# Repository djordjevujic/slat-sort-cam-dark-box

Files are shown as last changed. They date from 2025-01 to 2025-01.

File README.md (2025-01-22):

# slat-sort-cam-dark-box

Box used to hold a camera system, providing an initially dark environment and an adjustable lighting system.

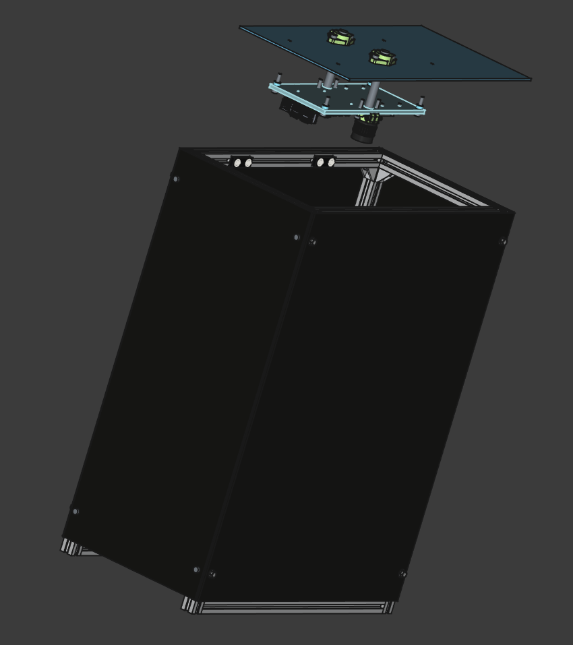
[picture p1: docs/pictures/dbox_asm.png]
Dark Box Assembly


## Project Overview

This project is developed in **FreeCAD 1.0.0**.

- **Main File**: The primary design file is `dbox_asm.FCStd`, located in the `assembly` folder.
- **Documentation**: Parts and material ordering documentation can be found in the `docs` folder.

## Features

- **Dark Environment**: Ensures initial dark conditions for precise image capture or experimentation.
- **Adjustable Lighting**: Includes a lighting system with customizable settings for controlled illumination.
- **Compact Design**: Optimized for portability and minimal footprint.
- **Light Isolation**: Prevents external light interference for consistent imaging.

## Applications

- Precision imaging for machine vision systems.
- Testing and calibrating camera sensors in controlled environments.
- Scientific experiments requiring adjustable lighting.

## Getting Started

### Prerequisites

- Install **FreeCAD 1.0.0** or a compatible version.
- Ensure all required materials and tools for assembly are available.

### Assembly Instructions

1. Open the `dbox_asm.FCStd` file in FreeCAD.
2. Follow the assembly instructions included in the `docs` folder.
3. Install the camera and lighting system inside the box.

## Usage

- Place the camera in the designated area within the box  - see `cam_holder_plate.FCStd`and `cam_holder_mount.FCStd`.
- Adjust the lighting system using the provided controls to meet your requirements.

## Documentation

- **Parts List and Material Ordering**: Detailed documentation is located in the `docs` folder.
  - Includes specifications for parts and ordering information.
  - Refer to the included files for a complete overview.

## License

This project is licensed under the **GNU General Public License (GPL)**. 

You are free to use, modify, and distribute the project under the terms of the GPL license. However, any derivative work must also be released under the same license. For more details, see the [GPL License](https://www.gnu.org/licenses/gpl-3.0.html).

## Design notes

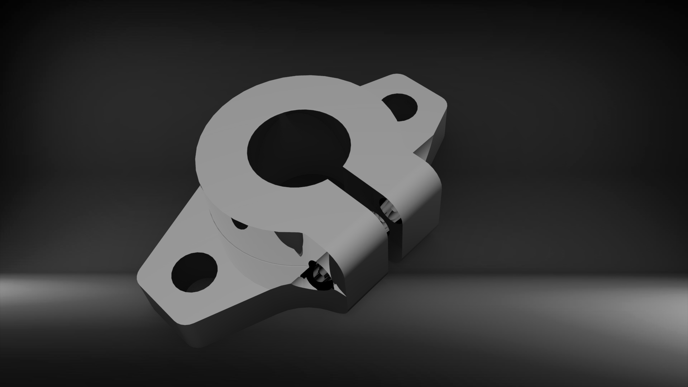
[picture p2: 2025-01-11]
downloads/linear-bearing-shaft-support-shf12-1.snapshot.1/SHF12 1.17.jpg

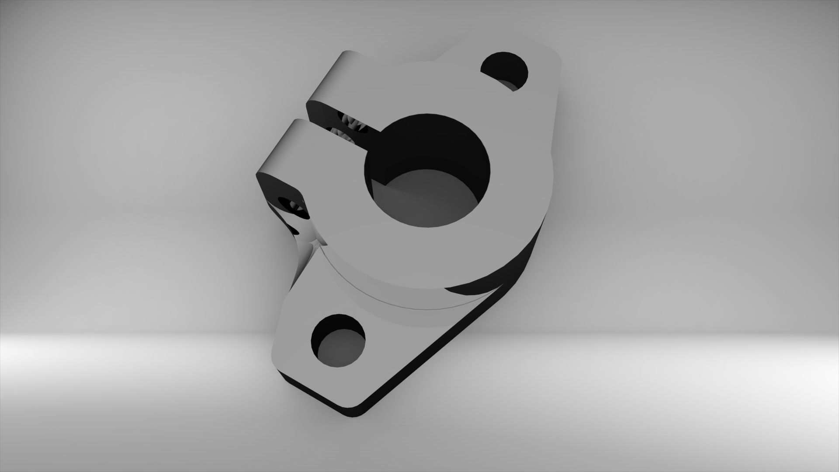
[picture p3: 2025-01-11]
downloads/linear-bearing-shaft-support-shf12-1.snapshot.1/SHF12 2.jpg

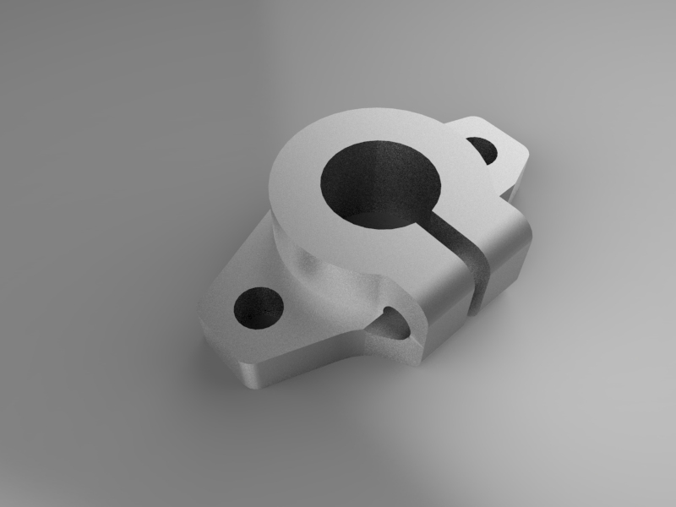
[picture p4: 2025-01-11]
downloads/linear-bearing-shaft-support-shf13-1.snapshot.1/SHF13 2.jpg

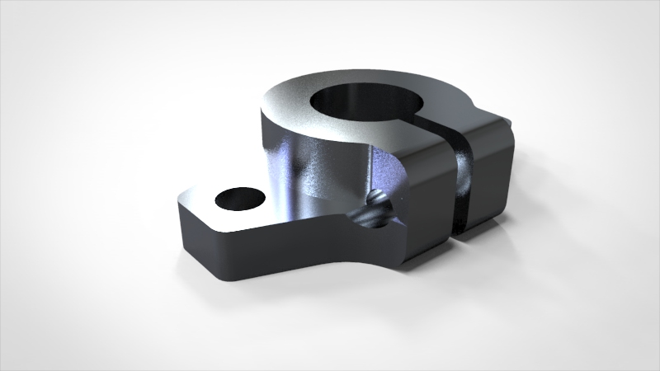
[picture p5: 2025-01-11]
downloads/linear-bearing-shaft-support-shf13-1.snapshot.1/SHF13 1.jpg

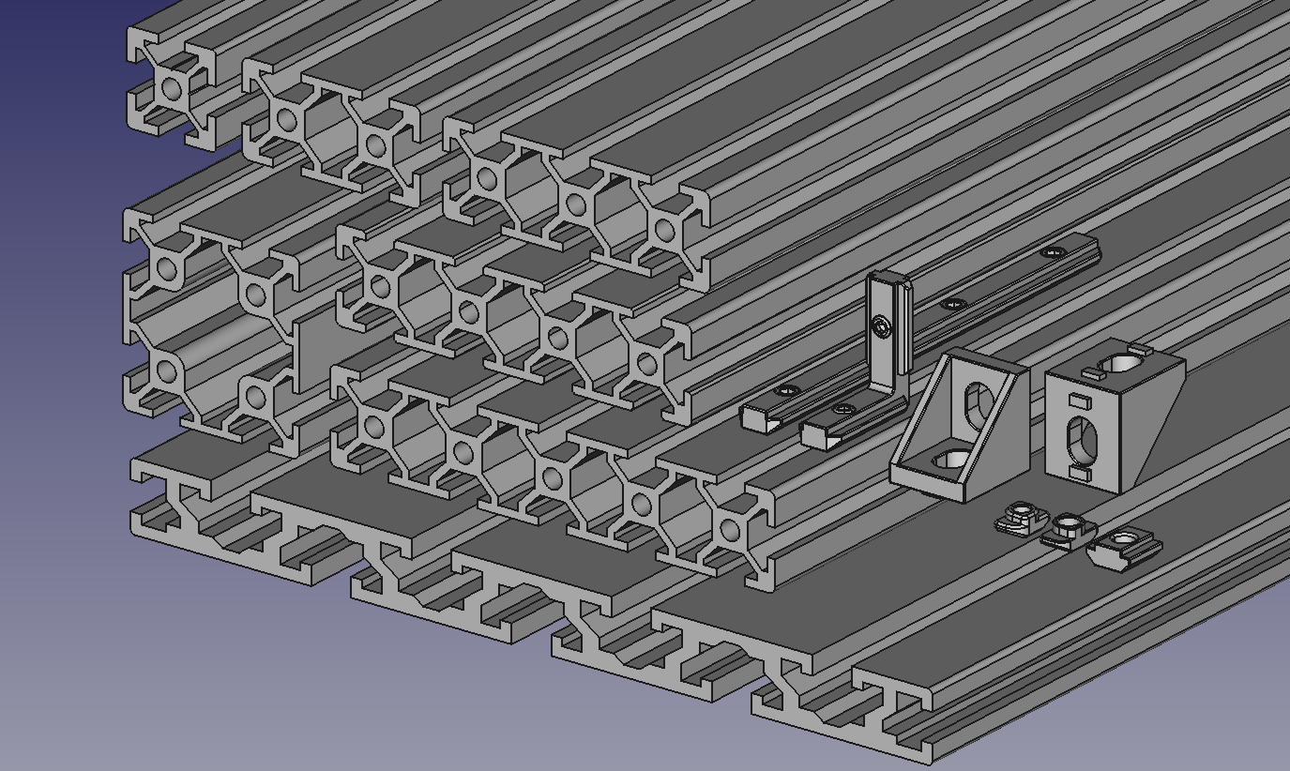
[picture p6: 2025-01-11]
downloads/2020-extrusions-fittings-1.snapshot.27/Set 1.png

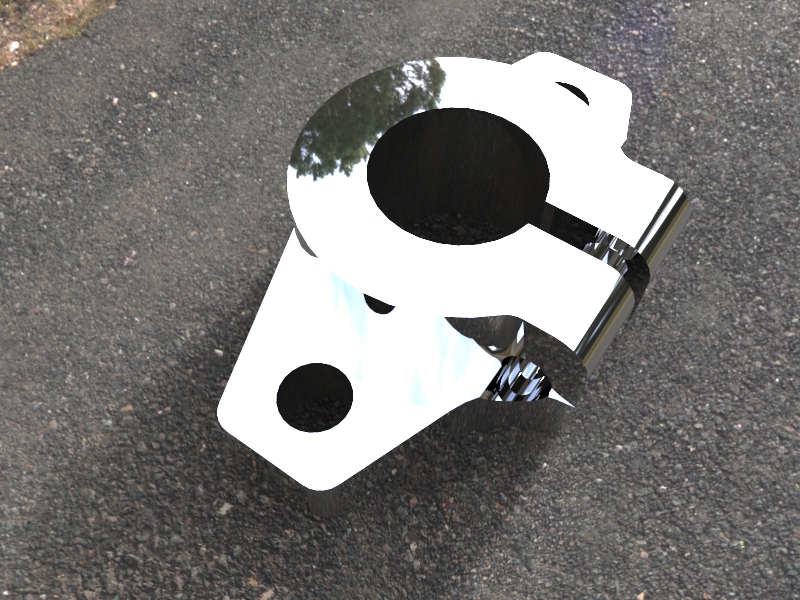
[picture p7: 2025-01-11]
downloads/linear-bearing-shaft-support-shf13-1.snapshot.1/SHF13 2.20.jpg

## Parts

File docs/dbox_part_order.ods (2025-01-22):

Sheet: T-prof Telix
Oznaka TELIX | Naziv | kom | cena kom | Cena uk | Komentar
ALP0020 | 3m Profil 20x20 | 2 | 7.08 | 14.16 | - cene se odnose na dužine 3 i 6m u komadu; kod sečenja na željenu dužinu cena se uvećava za 10% i naplaćuje se 0,3€ po rezu
ALP0612 | M5 T6 klizne navrtke | 40 | 0.2 | 8
ALP0150 | Vijak M5x10 | 80 | 0.11 | 8.8
ALP2120 | U. sp. za 20x20 | 16 | 0.61 | 9.76 | Treba koristiti vijke sa što nižom glavom. Najbolje je uzeti vijke sa sočivastom glavom. Za ovu spojnicu treba koristiti vijke sa sočivastom glavom M4x8 I zakretne navrtke
ALP0702 | Zk. nav. M5 T6 | 40 | 0.13 | 5.2 | - Koristice se za ugaone spojnice (16*2=32, plus za rezervu)
 | Kontaktirao Telix
 |  |  |  | 45.92

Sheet: Ostalo
Naziv | kom | cena kom | cena uk | link | Komentar
 | cam_holder
Vijak imbus ravna glava M5 L20 | 20 |  | 0 |  | Videti kod Buvaca
Vijak imbus ravna glava M5 L15 | 20 |  | 0 |  | Videti kod Buvaca
Vijak imbus ravna glava M4 L10 | 20 |  | 0 |  | Videti kod Buvaca
Vijak imbus ravna glava M4 L15 | 20 |  | 0 |  | Videti kod Buvaca
Vijak imbus ravna glava M4 L20 | 20 |  | 0 |  | Videti kod Buvaca
Navrtka M4 | 30 |  | 0 |  | Videti kod Buvaca
Navrtka M5 | 30 |  | 0 |  | Videti kod Buvaca
Vijak M2 |  | 0 | 0 | https://www.temu.com/goods.html?_bg_fs=1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
Vijak M2.5 4 | 15 | 0 | 0 | https://www.temu.com/goods.html?_bg_fs=1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
Vijak M3 |  | 0 | 0 | https://www.temu.com/goods.html?_bg_fs=1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
3D print insert M2.5 | 1 | 0 | 0 | https://www.temu.com/goods.html?_bg_fs=1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
3D print insert M3 | 1 | 25 | 25 | https://www.temu.com/goods.html?_bg_fs=1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
3D print insert M4 | 1 | 0 | 0 | https://www.temu.com/goods.html?_bg_fs=1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
Plexiglas |  |  | 0 |  | Kontaktirao europleksiglas.rs
Linearna vodjica fi12 L600 | 1 | 8 | 8 | https://www.cncshop.rs/delovi-i-oprema-za-cnc-masine/linearna-mehanika/linearne-vodjice-i-lezajevi/cilindricna-linearna-vodjica-fi-12/ | Kontaktirao optima.rs
Ukupno |  |  | 33

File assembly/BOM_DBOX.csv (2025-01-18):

Index | Name | Description | File Name | Quantity
1 | Tslot20_heigh |  | /home/djordje/Desktop/slat-sort-cam-dark-box/parts/T-Slot_20_height.FCStd | 4
2 | Tslot20_len |  | /home/djordje/Desktop/slat-sort-cam-dark-box/parts/T-Slot_20_length.FCStd | 4
3 | Tslot20_wid |  | /home/djordje/Desktop/slat-sort-cam-dark-box/parts/T-Slot_20_width.FCStd | 4
4 | Part_Bracket |  | /home/djordje/Desktop/slat-sort-cam-dark-box/downloads/2020-corner-bracket.FCStd | 16
4.1 | Body |  | /home/djordje/Desktop/slat-sort-cam-dark-box/downloads/2020-corner-bracket.FCStd | 1
5 | T-Nut_2020_M5 |  | /home/djordje/Desktop/slat-sort-cam-dark-box/parts/T-nut_20.FCStd | 56
6 | asm_roof_holder |  | /home/djordje/Desktop/slat-sort-cam-dark-box/assembly/dbox_asm.FCStd | 1
6.1 | asm_roof_holder |  | /home/djordje/Desktop/slat-sort-cam-dark-box/assembly/roof_holder_asm.FCStd | 1
6.1.1 | roof_holder |  | /home/djordje/Desktop/slat-sort-cam-dark-box/parts/roof_holder.FCStd | 2
6.1.2 | Hex socket countersunk head screw ISO 10642 M5 15.0 |  | /home/djordje/Desktop/slat-sort-cam-dark-box/assembly/dbox_asm.FCStd | 4
7 | asm_roof_holder001 |  | /home/djordje/Desktop/slat-sort-cam-dark-box/assembly/dbox_asm.FCStd | 1
7.1 | asm_roof_holder |  | /home/djordje/Desktop/slat-sort-cam-dark-box/assembly/roof_holder_asm.FCStd | 1
7.1.1 | roof_holder |  | /home/djordje/Desktop/slat-sort-cam-dark-box/parts/roof_holder.FCStd | 2
7.1.2 | Hex socket countersunk head screw ISO 10642 M5 15.0 |  | /home/djordje/Desktop/slat-sort-cam-dark-box/assembly/dbox_asm.FCStd | 4
8 | asm_roof_holder002 |  | /home/djordje/Desktop/slat-sort-cam-dark-box/assembly/dbox_asm.FCStd | 1
8.1 | asm_roof_holder |  | /home/djordje/Desktop/slat-sort-cam-dark-box/assembly/roof_holder_asm.FCStd | 1
8.1.1 | roof_holder |  | /home/djordje/Desktop/slat-sort-cam-dark-box/parts/roof_holder.FCStd | 2
8.1.2 | Hex socket countersunk head screw ISO 10642 M5 15.0 |  | /home/djordje/Desktop/slat-sort-cam-dark-box/assembly/dbox_asm.FCStd | 4
9 | asm_roof_holder003 |  | /home/djordje/Desktop/slat-sort-cam-dark-box/assembly/dbox_asm.FCStd | 1
9.1 | asm_roof_holder |  | /home/djordje/Desktop/slat-sort-cam-dark-box/assembly/roof_holder_asm.FCStd | 1
9.1.1 | roof_holder |  | /home/djordje/Desktop/slat-sort-cam-dark-box/parts/roof_holder.FCStd | 2
9.1.2 | Hex socket countersunk head screw ISO 10642 M5 15.0 |  | /home/djordje/Desktop/slat-sort-cam-dark-box/assembly/dbox_asm.FCStd | 4
10 | asm_roof |  | /home/djordje/Desktop/slat-sort-cam-dark-box/assembly/dbox_asm.FCStd | 1
10.1 | asm_roof |  | /home/djordje/Desktop/slat-sort-cam-dark-box/assembly/asm_roof.FCStd | 1
10.1.1 | plate_roof |  | /home/djordje/Desktop/slat-sort-cam-dark-box/parts/plate_roof.FCStd | 2
10.1.2 | linear_slide_12 |  | /home/djordje/Desktop/slat-sort-cam-dark-box/secondary/linear_slide.FCStd | 4
10.1.3 | asm_cam_holder |  | /home/djordje/Desktop/slat-sort-cam-dark-box/assembly/asm_cam_holder.FCStd | 2
10.1.3.1 | cam_holder_plate |  | /home/djordje/Desktop/slat-sort-cam-dark-box/parts/cam_holder/cam_holder_plate.FCStd | 1
10.1.3.2 | asm_SHF |  | /home/djordje/Desktop/slat-sort-cam-dark-box/assembly/asm_cam_holder.FCStd | 1
10.1.3.2.1 | asm_SHF |  | /home/djordje/Desktop/slat-sort-cam-dark-box/assembly/asm_shf.FCStd | 1
10.1.3.2.1.1 | SHF12 |  | /home/djordje/Desktop/slat-sort-cam-dark-box/downloads/linear-bearing-shaft-support-shf12-1.snapshot.1/SHF_12.FCStd | 2
10.1.3.2.1.2 | Hex socket head cap screw DIN 912 M4 15.0 |  | /home/djordje/Desktop/slat-sort-cam-dark-box/secondary/bolts.FCStd | 2
10.1.3.2.1.3 | Hex socket head cap screw DIN 912 M5 15.0 |  | /home/djordje/Desktop/slat-sort-cam-dark-box/secondary/bolts.FCStd | 8
10.1.3.3 | asm_SHF001 |  | /home/djordje/Desktop/slat-sort-cam-dark-box/assembly/asm_cam_holder.FCStd | 1
10.1.3.3.1 | asm_SHF |  | /home/djordje/Desktop/slat-sort-cam-dark-box/assembly/asm_shf.FCStd | 1
10.1.3.3.1.1 | SHF12 |  | /home/djordje/Desktop/slat-sort-cam-dark-box/downloads/linear-bearing-shaft-support-shf12-1.snapshot.1/SHF_12.FCStd | 2
10.1.3.3.1.2 | Hex socket head cap screw DIN 912 M4 15.0 |  | /home/djordje/Desktop/slat-sort-cam-dark-box/secondary/bolts.FCStd | 2
10.1.3.3.1.3 | Hex socket head cap screw DIN 912 M5 15.0 |  | /home/djordje/Desktop/slat-sort-cam-dark-box/secondary/bolts.FCStd | 4
10.1.3.4 | asm_rpi |  | /home/djordje/Desktop/slat-sort-cam-dark-box/assembly/asm_cam_holder.FCStd | 1
10.1.3.4.1 | asm_rpi |  | /home/djordje/Desktop/slat-sort-cam-dark-box/assembly/asm_rpi.FCStd | 1
10.1.3.4.1.1 | Raspberry Pi 4 Model B |  | /home/djordje/Desktop/slat-sort-cam-dark-box/downloads/raspberry_pi_4_model_b.FCStd | 2
10.1.3.4.1.1.1 | PCB, RPi4ModelB |  | /home/djordje/Desktop/slat-sort-cam-dark-box/downloads/raspberry_pi_4_model_b.FCStd | 1
10.1.3.4.1.1.2 | Broadcom BCM2711B0 CPU, RPi4ModelB002 |  | /home/djordje/Desktop/slat-sort-cam-dark-box/downloads/raspberry_pi_4_model_b.FCStd | 1
10.1.3.4.1.1.2.1 | Broadcom BCM2711B0 CPU, RPi4ModelB |  | /home/djordje/Desktop/slat-sort-cam-dark-box/downloads/raspberry_pi_4_model_b.FCStd | 1
10.1.3.4.1.1.2.2 | Broadcom BCM2711B0 CPU, RPi4ModelB001 |  | /home/djordje/Desktop/slat-sort-cam-dark-box/downloads/raspberry_pi_4_model_b.FCStd | 1
10.1.3.4.1.1.3 | 2.54 mm DUPONT MALE PIN HEADER, POE, 2X2, RPi4ModelB005 |  | /home/djordje/Desktop/slat-sort-cam-dark-box/downloads/raspberry_pi_4_model_b.FCStd | 1
10.1.3.4.1.1.3.1 | 2.54 mm DUPONT MALE PIN HEADER, POE, 2X2, RPi4ModelB |  | /home/djordje/Desktop/slat-sort-cam-dark-box/downloads/raspberry_pi_4_model_b.FCStd | 1
10.1.3.4.1.1.3.2 | 2.54 mm DUPONT MALE PIN HEADER, POE, 2X2, RPi4ModelB001 |  | /home/djordje/Desktop/slat-sort-cam-dark-box/downloads/raspberry_pi_4_model_b.FCStd | 1
10.1.3.4.1.1.3.3 | 2.54 mm DUPONT MALE PIN HEADER, POE, 2X2, RPi4ModelB002 |  | /home/djordje/Desktop/slat-sort-cam-dark-box/downloads/raspberry_pi_4_model_b.FCStd | 1
10.1.3.4.1.1.3.4 | 2.54 mm DUPONT MALE PIN HEADER, POE, 2X2, RPi4ModelB003 |  | /home/djordje/Desktop/slat-sort-cam-dark-box/downloads/raspberry_pi_4_model_b.FCStd | 1
10.1.3.4.1.1.3.5 | 2.54 mm DUPONT MALE PIN HEADER, POE, 2X2, RPi4ModelB004 |  | /home/djordje/Desktop/slat-sort-cam-dark-box/downloads/raspberry_pi_4_model_b.FCStd | 1
10.1.3.4.1.1.4 | 2.54 mm DUPONT MALE PIN HEADER, IO, 2X20, RPi4ModelB041 |  | /home/djordje/Desktop/slat-sort-cam-dark-box/downloads/raspberry_pi_4_model_b.FCStd | 1
10.1.3.4.1.1.4.1 | 2.54 mm DUPONT MALE PIN HEADER, IO, 2X20, RPi4ModelB |  | /home/djordje/Desktop/slat-sort-cam-dark-box/downloads/raspberry_pi_4_model_b.FCStd | 1
10.1.3.4.1.1.4.2 | 2.54 mm DUPONT MALE PIN HEADER, IO, 2X20, RPi4ModelB001 |  | /home/djordje/Desktop/slat-sort-cam-dark-box/downloads/raspberry_pi_4_model_b.FCStd | 1
10.1.3.4.1.1.4.3 | 2.54 mm DUPONT MALE PIN HEADER, IO, 2X20, RPi4ModelB002 |  | /home/djordje/Desktop/slat-sort-cam-dark-box/downloads/raspberry_pi_4_model_b.FCStd | 1
10.1.3.4.1.1.4.4 | 2.54 mm DUPONT MALE PIN HEADER, IO, 2X20, RPi4ModelB003 |  | /home/djordje/Desktop/slat-sort-cam-dark-box/downloads/raspberry_pi_4_model_b.FCStd | 1
10.1.3.4.1.1.4.5 | 2.54 mm DUPONT MALE PIN HEADER, IO, 2X20, RPi4ModelB004 |  | /home/djordje/Desktop/slat-sort-cam-dark-box/downloads/raspberry_pi_4_model_b.FCStd | 1
10.1.3.4.1.1.4.6 | 2.54 mm DUPONT MALE PIN HEADER, IO, 2X20, RPi4ModelB005 |  | /home/djordje/Desktop/slat-sort-cam-dark-box/downloads/raspberry_pi_4_model_b.FCStd | 1
10.1.3.4.1.1.4.7 | 2.54 mm DUPONT MALE PIN HEADER, IO, 2X20, RPi4ModelB006 |  | /home/djordje/Desktop/slat-sort-cam-dark-box/downloads/raspberry_pi_4_model_b.FCStd | 1
10.1.3.4.1.1.4.8 | 2.54 mm DUPONT MALE PIN HEADER, IO, 2X20, RPi4ModelB007 |  | /home/djordje/Desktop/slat-sort-cam-dark-box/downloads/raspberry_pi_4_model_b.FCStd | 1
10.1.3.4.1.1.4.9 | 2.54 mm DUPONT MALE PIN HEADER, IO, 2X20, RPi4ModelB008 |  | /home/djordje/Desktop/slat-sort-cam-dark-box/downloads/raspberry_pi_4_model_b.FCStd | 1
10.1.3.4.1.1.4.10 | 2.54 mm DUPONT MALE PIN HEADER, IO, 2X20, RPi4ModelB009 |  | /home/djordje/Desktop/slat-sort-cam-dark-box/downloads/raspberry_pi_4_model_b.FCStd | 1
10.1.3.4.1.1.4.11 | 2.54 mm DUPONT MALE PIN HEADER, IO, 2X20, RPi4ModelB010 |  | /home/djordje/Desktop/slat-sort-cam-dark-box/downloads/raspberry_pi_4_model_b.FCStd | 1
10.1.3.4.1.1.4.12 | 2.54 mm DUPONT MALE PIN HEADER, IO, 2X20, RPi4ModelB011 |  | /home/djordje/Desktop/slat-sort-cam-dark-box/downloads/raspberry_pi_4_model_b.FCStd | 1
10.1.3.4.1.1.4.13 | 2.54 mm DUPONT MALE PIN HEADER, IO, 2X20, RPi4ModelB012 |  | /home/djordje/Desktop/slat-sort-cam-dark-box/downloads/raspberry_pi_4_model_b.FCStd | 1
10.1.3.4.1.1.4.14 | 2.54 mm DUPONT MALE PIN HEADER, IO, 2X20, RPi4ModelB013 |  | /home/djordje/Desktop/slat-sort-cam-dark-box/downloads/raspberry_pi_4_model_b.FCStd | 1
10.1.3.4.1.1.4.15 | 2.54 mm DUPONT MALE PIN HEADER, IO, 2X20, RPi4ModelB014 |  | /home/djordje/Desktop/slat-sort-cam-dark-box/downloads/raspberry_pi_4_model_b.FCStd | 1
10.1.3.4.1.1.4.16 | 2.54 mm DUPONT MALE PIN HEADER, IO, 2X20, RPi4ModelB015 |  | /home/djordje/Desktop/slat-sort-cam-dark-box/downloads/raspberry_pi_4_model_b.FCStd | 1
10.1.3.4.1.1.4.17 | 2.54 mm DUPONT MALE PIN HEADER, IO, 2X20, RPi4ModelB016 |  | /home/djordje/Desktop/slat-sort-cam-dark-box/downloads/raspberry_pi_4_model_b.FCStd | 1
10.1.3.4.1.1.4.18 | 2.54 mm DUPONT MALE PIN HEADER, IO, 2X20, RPi4ModelB017 |  | /home/djordje/Desktop/slat-sort-cam-dark-box/downloads/raspberry_pi_4_model_b.FCStd | 1
10.1.3.4.1.1.4.19 | 2.54 mm DUPONT MALE PIN HEADER, IO, 2X20, RPi4ModelB018 |  | /home/djordje/Desktop/slat-sort-cam-dark-box/downloads/raspberry_pi_4_model_b.FCStd | 1
10.1.3.4.1.1.4.20 | 2.54 mm DUPONT MALE PIN HEADER, IO, 2X20, RPi4ModelB019 |  | /home/djordje/Desktop/slat-sort-cam-dark-box/downloads/raspberry_pi_4_model_b.FCStd | 1
10.1.3.4.1.1.4.21 | 2.54 mm DUPONT MALE PIN HEADER, IO, 2X20, RPi4ModelB020 |  | /home/djordje/Desktop/slat-sort-cam-dark-box/downloads/raspberry_pi_4_model_b.FCStd | 1
10.1.3.4.1.1.4.22 | 2.54 mm DUPONT MALE PIN HEADER, IO, 2X20, RPi4ModelB021 |  | /home/djordje/Desktop/slat-sort-cam-dark-box/downloads/raspberry_pi_4_model_b.FCStd | 1
10.1.3.4.1.1.4.23 | 2.54 mm DUPONT MALE PIN HEADER, IO, 2X20, RPi4ModelB022 |  | /home/djordje/Desktop/slat-sort-cam-dark-box/downloads/raspberry_pi_4_model_b.FCStd | 1
10.1.3.4.1.1.4.24 | 2.54 mm DUPONT MALE PIN HEADER, IO, 2X20, RPi4ModelB023 |  | /home/djordje/Desktop/slat-sort-cam-dark-box/downloads/raspberry_pi_4_model_b.FCStd | 1
10.1.3.4.1.1.4.25 | 2.54 mm DUPONT MALE PIN HEADER, IO, 2X20, RPi4ModelB024 |  | /home/djordje/Desktop/slat-sort-cam-dark-box/downloads/raspberry_pi_4_model_b.FCStd | 1
10.1.3.4.1.1.4.26 | 2.54 mm DUPONT MALE PIN HEADER, IO, 2X20, RPi4ModelB025 |  | /home/djordje/Desktop/slat-sort-cam-dark-box/downloads/raspberry_pi_4_model_b.FCStd | 1
10.1.3.4.1.1.4.27 | 2.54 mm DUPONT MALE PIN HEADER, IO, 2X20, RPi4ModelB026 |  | /home/djordje/Desktop/slat-sort-cam-dark-box/downloads/raspberry_pi_4_model_b.FCStd | 1
10.1.3.4.1.1.4.28 | 2.54 mm DUPONT MALE PIN HEADER, IO, 2X20, RPi4ModelB027 |  | /home/djordje/Desktop/slat-sort-cam-dark-box/downloads/raspberry_pi_4_model_b.FCStd | 1
10.1.3.4.1.1.4.29 | 2.54 mm DUPONT MALE PIN HEADER, IO, 2X20, RPi4ModelB028 |  | /home/djordje/Desktop/slat-sort-cam-dark-box/downloads/raspberry_pi_4_model_b.FCStd | 1
10.1.3.4.1.1.4.30 | 2.54 mm DUPONT MALE PIN HEADER, IO, 2X20, RPi4ModelB029 |  | /home/djordje/Desktop/slat-sort-cam-dark-box/downloads/raspberry_pi_4_model_b.FCStd | 1
10.1.3.4.1.1.4.31 | 2.54 mm DUPONT MALE PIN HEADER, IO, 2X20, RPi4ModelB030 |  | /home/djordje/Desktop/slat-sort-cam-dark-box/downloads/raspberry_pi_4_model_b.FCStd | 1
10.1.3.4.1.1.4.32 | 2.54 mm DUPONT MALE PIN HEADER, IO, 2X20, RPi4ModelB031 |  | /home/djordje/Desktop/slat-sort-cam-dark-box/downloads/raspberry_pi_4_model_b.FCStd | 1
10.1.3.4.1.1.4.33 | 2.54 mm DUPONT MALE PIN HEADER, IO, 2X20, RPi4ModelB032 |  | /home/djordje/Desktop/slat-sort-cam-dark-box/downloads/raspberry_pi_4_model_b.FCStd | 1
10.1.3.4.1.1.4.34 | 2.54 mm DUPONT MALE PIN HEADER, IO, 2X20, RPi4ModelB033 |  | /home/djordje/Desktop/slat-sort-cam-dark-box/downloads/raspberry_pi_4_model_b.FCStd | 1
10.1.3.4.1.1.4.35 | 2.54 mm DUPONT MALE PIN HEADER, IO, 2X20, RPi4ModelB034 |  | /home/djordje/Desktop/slat-sort-cam-dark-box/downloads/raspberry_pi_4_model_b.FCStd | 1
10.1.3.4.1.1.4.36 | 2.54 mm DUPONT MALE PIN HEADER, IO, 2X20, RPi4ModelB035 |  | /home/djordje/Desktop/slat-sort-cam-dark-box/downloads/raspberry_pi_4_model_b.FCStd | 1
10.1.3.4.1.1.4.37 | 2.54 mm DUPONT MALE PIN HEADER, IO, 2X20, RPi4ModelB036 |  | /home/djordje/Desktop/slat-sort-cam-dark-box/downloads/raspberry_pi_4_model_b.FCStd | 1
10.1.3.4.1.1.4.38 | 2.54 mm DUPONT MALE PIN HEADER, IO, 2X20, RPi4ModelB037 |  | /home/djordje/Desktop/slat-sort-cam-dark-box/downloads/raspberry_pi_4_model_b.FCStd | 1
10.1.3.4.1.1.4.39 | 2.54 mm DUPONT MALE PIN HEADER, IO, 2X20, RPi4ModelB038 |  | /home/djordje/Desktop/slat-sort-cam-dark-box/downloads/raspberry_pi_4_model_b.FCStd | 1
10.1.3.4.1.1.4.40 | 2.54 mm DUPONT MALE PIN HEADER, IO, 2X20, RPi4ModelB039 |  | /home/djordje/Desktop/slat-sort-cam-dark-box/downloads/raspberry_pi_4_model_b.FCStd | 1
10.1.3.4.1.1.4.41 | 2.54 mm DUPONT MALE PIN HEADER, IO, 2X20, RPi4ModelB040 |  | /home/djordje/Desktop/slat-sort-cam-dark-box/downloads/raspberry_pi_4_model_b.FCStd | 1
10.1.3.4.1.1.5 | Camera Connector, RPi4ModelB017 |  | /home/djordje/Desktop/slat-sort-cam-dark-box/downloads/raspberry_pi_4_model_b.FCStd | 1
10.1.3.4.1.1.5.1 | Camera Connector, RPi4ModelB |  | /home/djordje/Desktop/slat-sort-cam-dark-box/downloads/raspberry_pi_4_model_b.FCStd | 1
10.1.3.4.1.1.5.2 | Camera Connector, RPi4ModelB001 |  | /home/djordje/Desktop/slat-sort-cam-dark-box/downloads/raspberry_pi_4_model_b.FCStd | 1
10.1.3.4.1.1.5.3 | Camera Connector, RPi4ModelB002 |  | /home/djordje/Desktop/slat-sort-cam-dark-box/downloads/raspberry_pi_4_model_b.FCStd | 1
10.1.3.4.1.1.5.4 | Camera Connector, RPi4ModelB003 |  | /home/djordje/Desktop/slat-sort-cam-dark-box/downloads/raspberry_pi_4_model_b.FCStd | 1
10.1.3.4.1.1.5.5 | Camera Connector, RPi4ModelB004 |  | /home/djordje/Desktop/slat-sort-cam-dark-box/downloads/raspberry_pi_4_model_b.FCStd | 1
10.1.3.4.1.1.5.6 | Camera Connector, RPi4ModelB005 |  | /home/djordje/Desktop/slat-sort-cam-dark-box/downloads/raspberry_pi_4_model_b.FCStd | 1
10.1.3.4.1.1.5.7 | Camera Connector, RPi4ModelB006 |  | /home/djordje/Desktop/slat-sort-cam-dark-box/downloads/raspberry_pi_4_model_b.FCStd | 1
10.1.3.4.1.1.5.8 | Camera Connector, RPi4ModelB007 |  | /home/djordje/Desktop/slat-sort-cam-dark-box/downloads/raspberry_pi_4_model_b.FCStd | 1
10.1.3.4.1.1.5.9 | Camera Connector, RPi4ModelB008 |  | /home/djordje/Desktop/slat-sort-cam-dark-box/downloads/raspberry_pi_4_model_b.FCStd | 1
10.1.3.4.1.1.5.10 | Camera Connector, RPi4ModelB009 |  | /home/djordje/Desktop/slat-sort-cam-dark-box/downloads/raspberry_pi_4_model_b.FCStd | 1
10.1.3.4.1.1.5.11 | Camera Connector, RPi4ModelB010 |  | /home/djordje/Desktop/slat-sort-cam-dark-box/downloads/raspberry_pi_4_model_b.FCStd | 1
10.1.3.4.1.1.5.12 | Camera Connector, RPi4ModelB011 |  | /home/djordje/Desktop/slat-sort-cam-dark-box/downloads/raspberry_pi_4_model_b.FCStd | 1
10.1.3.4.1.1.5.13 | Camera Connector, RPi4ModelB012 |  | /home/djordje/Desktop/slat-sort-cam-dark-box/downloads/raspberry_pi_4_model_b.FCStd | 1
10.1.3.4.1.1.5.14 | Camera Connector, RPi4ModelB013 |  | /home/djordje/Desktop/slat-sort-cam-dark-box/downloads/raspberry_pi_4_model_b.FCStd | 1
10.1.3.4.1.1.5.15 | Camera Connector, RPi4ModelB014 |  | /home/djordje/Desktop/slat-sort-cam-dark-box/downloads/raspberry_pi_4_model_b.FCStd | 1
10.1.3.4.1.1.5.16 | Camera Connector, RPi4ModelB015 |  | /home/djordje/Desktop/slat-sort-cam-dark-box/downloads/raspberry_pi_4_model_b.FCStd | 1
10.1.3.4.1.1.5.17 | Camera Connector, RPi4ModelB016 |  | /home/djordje/Desktop/slat-sort-cam-dark-box/downloads/raspberry_pi_4_model_b.FCStd | 1
10.1.3.4.1.1.6 | Microphone Plug, RPi4ModelB005 |  | /home/djordje/Desktop/slat-sort-cam-dark-box/downloads/raspberry_pi_4_model_b.FCStd | 1
10.1.3.4.1.1.6.1 | Microphone Plug, RPi4ModelB |  | /home/djordje/Desktop/slat-sort-cam-dark-box/downloads/raspberry_pi_4_model_b.FCStd | 1
10.1.3.4.1.1.6.2 | Microphone Plug, RPi4ModelB001 |  | /home/djordje/Desktop/slat-sort-cam-dark-box/downloads/raspberry_pi_4_model_b.FCStd | 1
10.1.3.4.1.1.6.3 | Microphone Plug, RPi4ModelB002 |  | /home/djordje/Desktop/slat-sort-cam-dark-box/downloads/raspberry_pi_4_model_b.FCStd | 1
10.1.3.4.1.1.6.4 | Microphone Plug, RPi4ModelB003 |  | /home/djordje/Desktop/slat-sort-cam-dark-box/downloads/raspberry_pi_4_model_b.FCStd | 1
10.1.3.4.1.1.6.5 | Microphone Plug, RPi4ModelB004 |  | /home/djordje/Desktop/slat-sort-cam-dark-box/downloads/raspberry_pi_4_model_b.FCStd | 1
10.1.3.4.1.1.7 | Display Connector, RPi4ModelB017 |  | /home/djordje/Desktop/slat-sort-cam-dark-box/downloads/raspberry_pi_4_model_b.FCStd | 1
10.1.3.4.1.1.7.1 | Display Connector, RPi4ModelB |  | /home/djordje/Desktop/slat-sort-cam-dark-box/downloads/raspberry_pi_4_model_b.FCStd | 1
10.1.3.4.1.1.7.2 | Display Connector, RPi4ModelB001 |  | /home/djordje/Desktop/slat-sort-cam-dark-box/downloads/raspberry_pi_4_model_b.FCStd | 1
10.1.3.4.1.1.7.3 | Display Connector, RPi4ModelB002 |  | /home/djordje/Desktop/slat-sort-cam-dark-box/downloads/raspberry_pi_4_model_b.FCStd | 1
10.1.3.4.1.1.7.4 | Display Connector, RPi4ModelB003 |  | /home/djordje/Desktop/slat-sort-cam-dark-box/downloads/raspberry_pi_4_model_b.FCStd | 1
10.1.3.4.1.1.7.5 | Display Connector, RPi4ModelB004 |  | /home/djordje/Desktop/slat-sort-cam-dark-box/downloads/raspberry_pi_4_model_b.FCStd | 1
10.1.3.4.1.1.7.6 | Display Connector, RPi4ModelB005 |  | /home/djordje/Desktop/slat-sort-cam-dark-box/downloads/raspberry_pi_4_model_b.FCStd | 1
10.1.3.4.1.1.7.7 | Display Connector, RPi4ModelB006 |  | /home/djordje/Desktop/slat-sort-cam-dark-box/downloads/raspberry_pi_4_model_b.FCStd | 1
10.1.3.4.1.1.7.8 | Display Connector, RPi4ModelB007 |  | /home/djordje/Desktop/slat-sort-cam-dark-box/downloads/raspberry_pi_4_model_b.FCStd | 1
10.1.3.4.1.1.7.9 | Display Connector, RPi4ModelB008 |  | /home/djordje/Desktop/slat-sort-cam-dark-box/downloads/raspberry_pi_4_model_b.FCStd | 1
10.1.3.4.1.1.7.10 | Display Connector, RPi4ModelB009 |  | /home/djordje/Desktop/slat-sort-cam-dark-box/downloads/raspberry_pi_4_model_b.FCStd | 1
10.1.3.4.1.1.7.11 | Display Connector, RPi4ModelB010 |  | /home/djordje/Desktop/slat-sort-cam-dark-box/downloads/raspberry_pi_4_model_b.FCStd | 1
10.1.3.4.1.1.7.12 | Display Connector, RPi4ModelB011 |  | /home/djordje/Desktop/slat-sort-cam-dark-box/downloads/raspberry_pi_4_model_b.FCStd | 1
10.1.3.4.1.1.7.13 | Display Connector, RPi4ModelB012 |  | /home/djordje/Desktop/slat-sort-cam-dark-box/downloads/raspberry_pi_4_model_b.FCStd | 1
10.1.3.4.1.1.7.14 | Display Connector, RPi4ModelB013 |  | /home/djordje/Desktop/slat-sort-cam-dark-box/downloads/raspberry_pi_4_model_b.FCStd | 1
10.1.3.4.1.1.7.15 | Display Connector, RPi4ModelB014 |  | /home/djordje/Desktop/slat-sort-cam-dark-box/downloads/raspberry_pi_4_model_b.FCStd | 1
10.1.3.4.1.1.7.16 | Display Connector, RPi4ModelB015 |  | /home/djordje/Desktop/slat-sort-cam-dark-box/downloads/raspberry_pi_4_model_b.FCStd | 1
10.1.3.4.1.1.7.17 | Display Connector, RPi4ModelB016 |  | /home/djordje/Desktop/slat-sort-cam-dark-box/downloads/raspberry_pi_4_model_b.FCStd | 1
10.1.3.4.1.1.8 | Gigabit Ethernet Port, RPi4ModelB |  | /home/djordje/Desktop/slat-sort-cam-dark-box/downloads/raspberry_pi_4_model_b.FCStd | 1
10.1.3.4.1.1.9 | Female Micro HDMI Connector, RPi4ModelB |  | /home/djordje/Desktop/slat-sort-cam-dark-box/downloads/raspberry_pi_4_model_b.FCStd | 1
10.1.3.4.1.1.10 | Female Micro HDMI Connector, RPi4ModelB001 |  | /home/djordje/Desktop/slat-sort-cam-dark-box/downloads/raspberry_pi_4_model_b.FCStd | 1
10.1.3.4.1.1.11 | Female USB Type C Connector, RPi4ModelB |  | /home/djordje/Desktop/slat-sort-cam-dark-box/downloads/raspberry_pi_4_model_b.FCStd | 1
10.1.3.4.1.1.12 | 2X USB3.0 PORTS, RPi4ModelB |  | /home/djordje/Desktop/slat-sort-cam-dark-box/downloads/raspberry_pi_4_model_b.FCStd | 1
10.1.3.4.1.1.13 | 91D77 D9WHV 778K, 4 GB LPDDR4 SDRAM, RPi4ModelB |  | /home/djordje/Desktop/slat-sort-cam-dark-box/downloads/raspberry_pi_4_model_b.FCStd | 1
10.1.3.4.1.1.14 | Cypress CYW43455 Wireless Module Cover, RPi4ModelB |  | /home/djordje/Desktop/slat-sort-cam-dark-box/downloads/raspberry_pi_4_model_b.FCStd | 1
10.1.3.4.1.1.15 | SD Card Slot, RPi4ModelB010 |  | /home/djordje/Desktop/slat-sort-cam-dark-box/downloads/raspberry_pi_4_model_b.FCStd | 1
10.1.3.4.1.1.15.1 | SD Card Slot, RPi4ModelB |  | /home/djordje/Desktop/slat-sort-cam-dark-box/downloads/raspberry_pi_4_model_b.FCStd | 1
10.1.3.4.1.1.15.2 | SD Card Slot, RPi4ModelB001 |  | /home/djordje/Desktop/slat-sort-cam-dark-box/downloads/raspberry_pi_4_model_b.FCStd | 1
10.1.3.4.1.1.15.3 | SD Card Slot, RPi4ModelB002 |  | /home/djordje/Desktop/slat-sort-cam-dark-box/downloads/raspberry_pi_4_model_b.FCStd | 1
10.1.3.4.1.1.15.4 | SD Card Slot, RPi4ModelB003 |  | /home/djordje/Desktop/slat-sort-cam-dark-box/downloads/raspberry_pi_4_model_b.FCStd | 1
10.1.3.4.1.1.15.5 | SD Card Slot, RPi4ModelB004 |  | /home/djordje/Desktop/slat-sort-cam-dark-box/downloads/raspberry_pi_4_model_b.FCStd | 1
10.1.3.4.1.1.15.6 | SD Card Slot, RPi4ModelB005 |  | /home/djordje/Desktop/slat-sort-cam-dark-box/downloads/raspberry_pi_4_model_b.FCStd | 1
10.1.3.4.1.1.15.7 | SD Card Slot, RPi4ModelB006 |  | /home/djordje/Desktop/slat-sort-cam-dark-box/downloads/raspberry_pi_4_model_b.FCStd | 1
10.1.3.4.1.1.15.8 | SD Card Slot, RPi4ModelB007 |  | /home/djordje/Desktop/slat-sort-cam-dark-box/downloads/raspberry_pi_4_model_b.FCStd | 1
10.1.3.4.1.1.15.9 | SD Card Slot, RPi4ModelB008 |  | /home/djordje/Desktop/slat-sort-cam-dark-box/downloads/raspberry_pi_4_model_b.FCStd | 1
10.1.3.4.1.1.15.10 | SD Card Slot, RPi4ModelB009 |  | /home/djordje/Desktop/slat-sort-cam-dark-box/downloads/raspberry_pi_4_model_b.FCStd | 1
10.1.3.4.1.1.16 | VIA VL805 PCIe USB 3.0 controller, RPi4ModelB |  | /home/djordje/Desktop/slat-sort-cam-dark-box/downloads/raspberry_pi_4_model_b.FCStd | 1
10.1.3.4.1.1.17 | 2X USB2.0 PORTS, RPi4ModelB |  | /home/djordje/Desktop/slat-sort-cam-dark-box/downloads/raspberry_pi_4_model_b.FCStd | 1
10.1.3.4.1.1.18 | Broadcom BCM54213PE Gigabit Ethernet Transceiver, RPi4ModelB |  | /home/djordje/Desktop/slat-sort-cam-dark-box/downloads/raspberry_pi_4_model_b.FCStd | 1
10.1.3.4.1.1.19 | MxL7704 Universal PMIC, RPi4ModelB |  | /home/djordje/Desktop/slat-sort-cam-dark-box/downloads/raspberry_pi_4_model_b.FCStd | 1
10.1.3.4.1.2 | Hex screw M2.5 04.0 |  | /home/djordje/Desktop/slat-sort-cam-dark-box/secondary/bolts.FCStd | 8
10.1.3.5 | asm_cam_mount |  | /home/djordje/Desktop/slat-sort-cam-dark-box/assembly/asm_cam_holder.FCStd | 1
10.1.3.5.1 | asm_cam_mount |  | /home/djordje/Desktop/slat-sort-cam-dark-box/assembly/asm_cam_mount.FCStd | 1
10.1.3.5.1.1 | cam_holder_base |  | /home/djordje/Desktop/slat-sort-cam-dark-box/parts/cam_holder/cam_holder_base.FCStd | 2
10.1.3.5.1.2 | Raspberry Pi HQ Camera with cs mount lens v014 |  | /home/djordje/Desktop/slat-sort-cam-dark-box/downloads/raspberry_pi_camera.FCStd | 2
10.1.3.5.1.2.1 | Raspberry Pi HQ Camera with cs mount lens v3 |  | /home/djordje/Desktop/slat-sort-cam-dark-box/downloads/raspberry_pi_camera.FCStd | 1
10.1.3.5.1.2.2 | Raspberry Pi HQ Camera with cs mount lens v004 |  | /home/djordje/Desktop/slat-sort-cam-dark-box/downloads/raspberry_pi_camera.FCStd | 1
10.1.3.5.1.2.3 | Raspberry Pi HQ Camera with cs mount lens v005 |  | /home/djordje/Desktop/slat-sort-cam-dark-box/downloads/raspberry_pi_camera.FCStd | 1
10.1.3.5.1.2.4 | Raspberry Pi HQ Camera with cs mount lens v006 |  | /home/djordje/Desktop/slat-sort-cam-dark-box/downloads/raspberry_pi_camera.FCStd | 1
10.1.3.5.1.2.5 | Raspberry Pi HQ Camera with cs mount lens v007 |  | /home/djordje/Desktop/slat-sort-cam-dark-box/downloads/raspberry_pi_camera.FCStd | 1
10.1.3.5.1.2.6 | Raspberry Pi HQ Camera with cs mount lens v008 |  | /home/djordje/Desktop/slat-sort-cam-dark-box/downloads/raspberry_pi_camera.FCStd | 1
10.1.3.5.1.2.7 | Raspberry Pi HQ Camera with cs mount lens v009 |  | /home/djordje/Desktop/slat-sort-cam-dark-box/downloads/raspberry_pi_camera.FCStd | 1
10.1.3.5.1.2.8 | Raspberry Pi HQ Camera with cs mount lens v010 |  | /home/djordje/Desktop/slat-sort-cam-dark-box/downloads/raspberry_pi_camera.FCStd | 1
10.1.3.5.1.2.9 | Raspberry Pi HQ Camera with cs mount lens v011 |  | /home/djordje/Desktop/slat-sort-cam-dark-box/downloads/raspberry_pi_camera.FCStd | 1
10.1.3.5.1.2.10 | Raspberry Pi HQ Camera with cs mount lens v012 |  | /home/djordje/Desktop/slat-sort-cam-dark-box/downloads/raspberry_pi_camera.FCStd | 1
10.1.3.5.1.2.11 | Raspberry Pi HQ Camera with cs mount lens v013 |  | /home/djordje/Desktop/slat-sort-cam-dark-box/downloads/raspberry_pi_camera.FCStd | 1
10.1.3.5.1.3 | Hex screw M2.5 04.0 |  | /home/djordje/Desktop/slat-sort-cam-dark-box/secondary/bolts.FCStd | 8
10.1.3.5.1.4 | Hex screw M4 10.0 |  | /home/djordje/Desktop/slat-sort-cam-dark-box/secondary/bolts.FCStd | 8
10.1.3.6 | plate_holder |  | /home/djordje/Desktop/slat-sort-cam-dark-box/parts/plate_holder.FCStd | 4
10.1.4 | asm_SHF002 |  | /home/djordje/Desktop/slat-sort-cam-dark-box/assembly/asm_roof.FCStd | 1
10.1.4.1 | asm_SHF |  | /home/djordje/Desktop/slat-sort-cam-dark-box/assembly/asm_shf.FCStd | 1
10.1.4.1.1 | SHF12 |  | /home/djordje/Desktop/slat-sort-cam-dark-box/downloads/linear-bearing-shaft-support-shf12-1.snapshot.1/SHF_12.FCStd | 2
10.1.4.1.2 | Hex socket head cap screw DIN 912 M4 15.0 |  | /home/djordje/Desktop/slat-sort-cam-dark-box/secondary/bolts.FCStd | 2
10.1.4.1.3 | Hex socket head cap screw DIN 912 M5 15.0 |  | /home/djordje/Desktop/slat-sort-cam-dark-box/secondary/bolts.FCStd | 4
10.1.5 | asm_SHF003 |  | /home/djordje/Desktop/slat-sort-cam-dark-box/assembly/asm_roof.FCStd | 1
10.1.5.1 | asm_SHF |  | /home/djordje/Desktop/slat-sort-cam-dark-box/assembly/asm_shf.FCStd | 1
10.1.5.1.1 | SHF12 |  | /home/djordje/Desktop/slat-sort-cam-dark-box/downloads/linear-bearing-shaft-support-shf12-1.snapshot.1/SHF_12.FCStd | 2
10.1.5.1.2 | Hex socket head cap screw DIN 912 M4 15.0 |  | /home/djordje/Desktop/slat-sort-cam-dark-box/secondary/bolts.FCStd | 2
10.1.5.1.3 | Hex socket head cap screw DIN 912 M5 15.0 |  | /home/djordje/Desktop/slat-sort-cam-dark-box/secondary/bolts.FCStd | 4
10.1.6 | Hexagonal Nut M5_CBALN5 |  | /home/djordje/Desktop/slat-sort-cam-dark-box/secondary/nuts_hexagonal.FCStd | 8
10.1.7 | Hexagonal Nut M4_CBALN4 |  | /home/djordje/Desktop/slat-sort-cam-dark-box/secondary/nuts_hexagonal.FCStd | 8
10.2 | asm_SHF002 |  | /home/djordje/Desktop/slat-sort-cam-dark-box/assembly/dbox_asm.FCStd | 1
10.2.1 | asm_SHF002 |  | /home/djordje/Desktop/slat-sort-cam-dark-box/assembly/asm_roof.FCStd | 1
10.2.1.1 | asm_SHF |  | /home/djordje/Desktop/slat-sort-cam-dark-box/assembly/asm_shf.FCStd | 1
10.2.1.1.1 | SHF12 |  | /home/djordje/Desktop/slat-sort-cam-dark-box/downloads/linear-bearing-shaft-support-shf12-1.snapshot.1/SHF_12.FCStd | 3
10.2.1.1.2 | Hex socket head cap screw DIN 912 M4 15.0 |  | /home/djordje/Desktop/slat-sort-cam-dark-box/secondary/bolts.FCStd | 3
10.2.1.1.3 | Hex socket head cap screw DIN 912 M5 15.0 |  | /home/djordje/Desktop/slat-sort-cam-dark-box/secondary/bolts.FCStd | 6
10.3 | asm_SHF003 |  | /home/djordje/Desktop/slat-sort-cam-dark-box/assembly/dbox_asm.FCStd | 1
10.3.1 | asm_SHF003 |  | /home/djordje/Desktop/slat-sort-cam-dark-box/assembly/asm_roof.FCStd | 1
10.3.1.1 | asm_SHF |  | /home/djordje/Desktop/slat-sort-cam-dark-box/assembly/asm_shf.FCStd | 1
10.3.1.1.1 | SHF12 |  | /home/djordje/Desktop/slat-sort-cam-dark-box/downloads/linear-bearing-shaft-support-shf12-1.snapshot.1/SHF_12.FCStd | 3
10.3.1.1.2 | Hex socket head cap screw DIN 912 M4 15.0 |  | /home/djordje/Desktop/slat-sort-cam-dark-box/secondary/bolts.FCStd | 3
10.3.1.1.3 | Hex socket head cap screw DIN 912 M5 15.0 |  | /home/djordje/Desktop/slat-sort-cam-dark-box/secondary/bolts.FCStd | 6
11 | asm_plate_front_back |  | /home/djordje/Desktop/slat-sort-cam-dark-box/assembly/dbox_asm.FCStd | 1
11.1 | asm_plate_front_back |  | /home/djordje/Desktop/slat-sort-cam-dark-box/assembly/asm_plate_front_back.FCStd | 1
11.1.1 | plate_front_back |  | /home/djordje/Desktop/slat-sort-cam-dark-box/parts/plate_front_back.FCStd | 2
11.1.2 | Hex screw M5 10.0 |  | /home/djordje/Desktop/slat-sort-cam-dark-box/secondary/bolts.FCStd | 41
12 | asm_plate_front_back001 |  | /home/djordje/Desktop/slat-sort-cam-dark-box/assembly/dbox_asm.FCStd | 1
12.1 | asm_plate_front_back |  | /home/djordje/Desktop/slat-sort-cam-dark-box/assembly/asm_plate_front_back.FCStd | 1
12.1.1 | plate_front_back |  | /home/djordje/Desktop/slat-sort-cam-dark-box/parts/plate_front_back.FCStd | 2
12.1.2 | Hex screw M5 10.0 |  | /home/djordje/Desktop/slat-sort-cam-dark-box/secondary/bolts.FCStd | 8
13 | asm_plate_side |  | /home/djordje/Desktop/slat-sort-cam-dark-box/assembly/dbox_asm.FCStd | 1
13.1 | asm_plate_side |  | /home/djordje/Desktop/slat-sort-cam-dark-box/assembly/asm_plate_side.FCStd | 1
13.1.1 | plate_side |  | /home/djordje/Desktop/slat-sort-cam-dark-box/parts/plate_side.FCStd | 2
13.1.2 | TAH15-M5-L6 |  | /home/djordje/Desktop/slat-sort-cam-dark-box/secondary/TAH15_M5_L6.FCStd | 8
14 | asm_plate_side001 |  | /home/djordje/Desktop/slat-sort-cam-dark-box/assembly/dbox_asm.FCStd | 1
14.1 | asm_plate_side |  | /home/djordje/Desktop/slat-sort-cam-dark-box/assembly/asm_plate_side.FCStd | 1
14.1.1 | plate_side |  | /home/djordje/Desktop/slat-sort-cam-dark-box/parts/plate_side.FCStd | 2
14.1.2 | TAH15-M5-L6 |  | /home/djordje/Desktop/slat-sort-cam-dark-box/secondary/TAH15_M5_L6.FCStd | 8

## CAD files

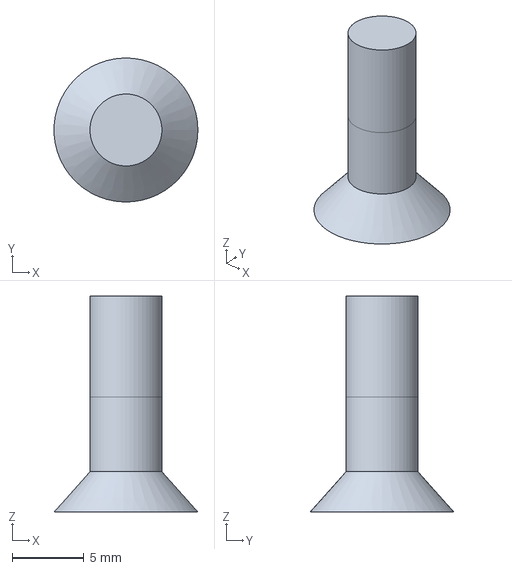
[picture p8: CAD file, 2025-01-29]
assembly/dbox_asm.FCStd
9.99 x 10.00 x 15.0 mm

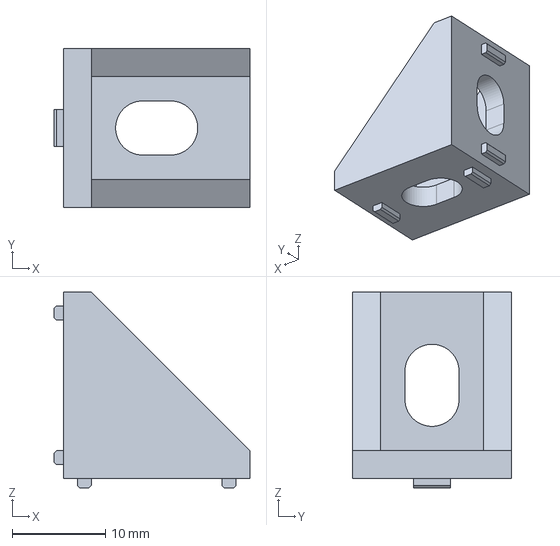
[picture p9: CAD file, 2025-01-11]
downloads/2020-corner-bracket.FCStd
21.0 x 17.0 x 21.0 mm

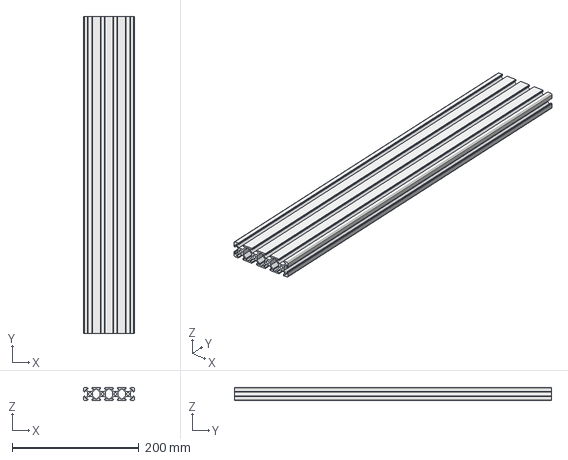
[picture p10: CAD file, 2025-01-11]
downloads/2020-extrusions-fittings-1.snapshot.27/FreeCAD Files/2080 Extrusion Detailed.FCStd
80.0 x 500.0 x 20.0 mm

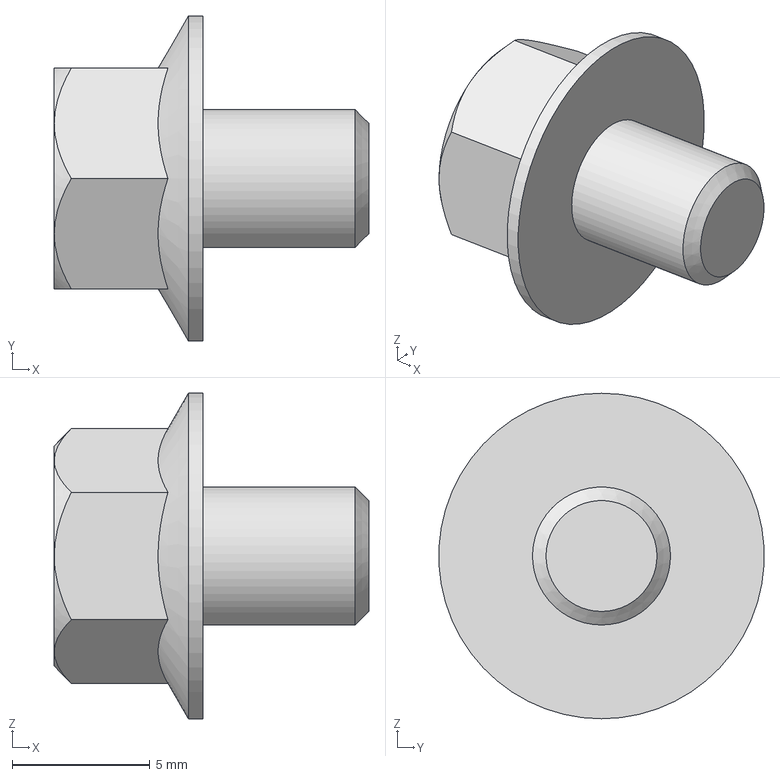
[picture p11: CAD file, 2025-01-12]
downloads/3dfindit-Yiheda_3D_Electronic_Gallery-TAH15-M5-L6-0202501121845209724530210e898ce/TAH15-M5-L6.stp
11.4 x 11.8 x 11.8 mm

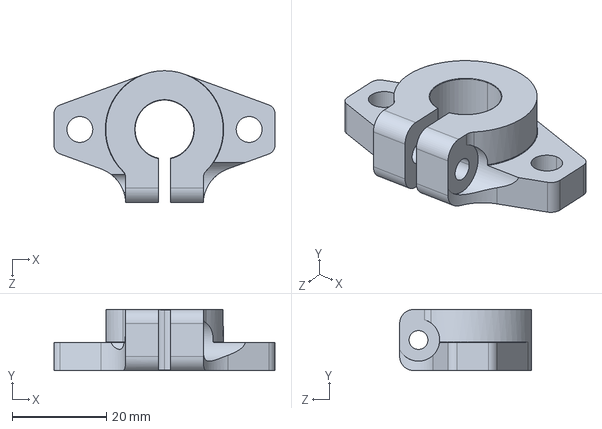
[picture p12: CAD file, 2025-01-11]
downloads/linear-bearing-shaft-support-shf12-1.snapshot.1/SHF12.STEP
47.0 x 13.0 x 28.0 mm

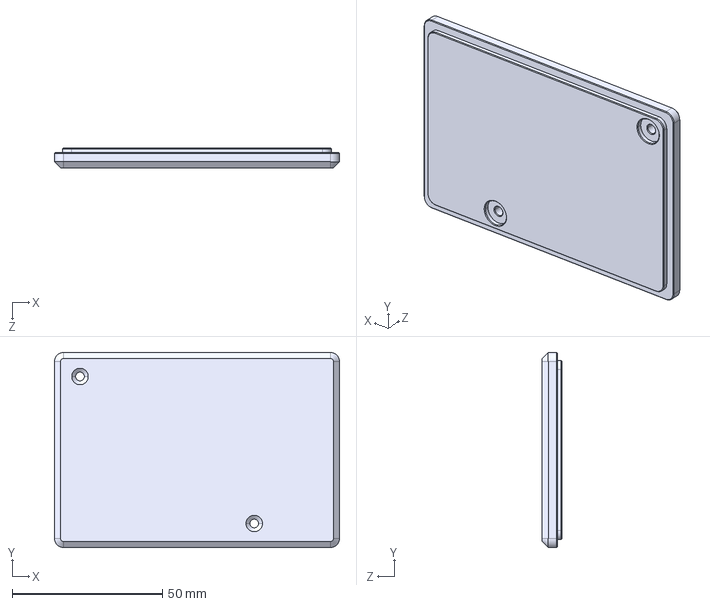
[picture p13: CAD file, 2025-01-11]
downloads/raspberry-pi5-machine-vision-camera-case-1.snapshot.10/RPI-002 RPICAM ENCLOSURE BACK.STEP
95.0 x 65.0 x 6.50 mm

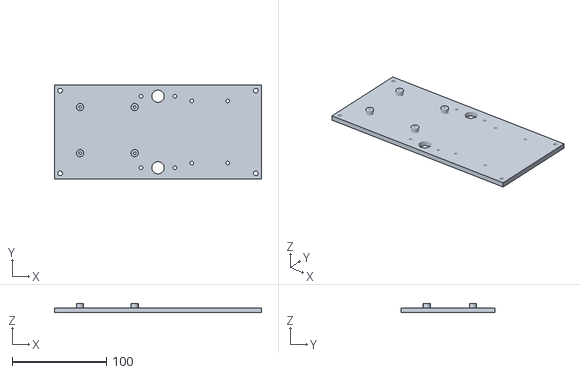
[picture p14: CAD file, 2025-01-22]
exported_print/cam_holder_plate/cam_holder_plate-cam_holder_plate.stl
220.0 x 100.0 x 10.0

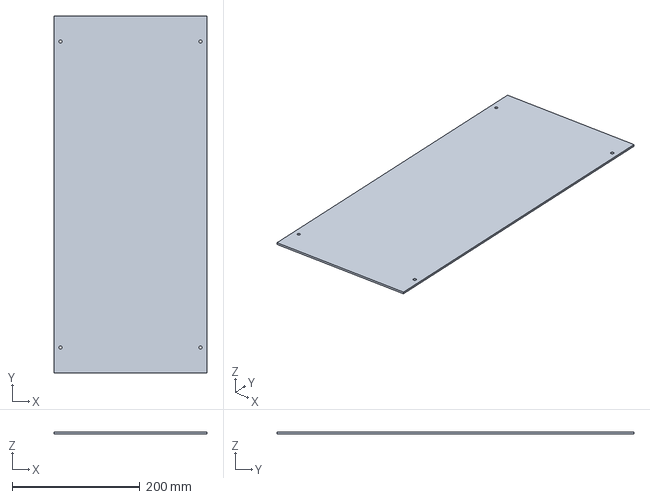
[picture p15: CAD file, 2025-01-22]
exported_step/plate_front_back-plate_front_back.step
240.0 x 560.0 x 3.00 mm

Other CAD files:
assembly/asm_cam_holder.FCStd
assembly/roof_holder_asm.FCStd
assembly/asm_roof.FCStd
secondary/top_edge_case_asm.FCStd
assembly/asm_plate_front_back.FCStd
assembly/asm_plate_side.FCStd
assembly/asm_shf.FCStd
assembly/asm_rpi.FCStd
assembly/asm_cam_mount.FCStd
downloads/linear-bearing-shaft-support-shf13-1.snapshot.1/SHF13.STEP
backup/dbox_asm_skelet_and_corners.FCStd
backup/dbox_asm_skeleton.FCStd
downloads/2020-extrusions-fittings-1.snapshot.27/20100 Extrusion.step
downloads/2020-extrusions-fittings-1.snapshot.27/2020 Corner Bracket.step
downloads/2020-extrusions-fittings-1.snapshot.27/2020 Extrusion 500mm.step
downloads/2020-extrusions-fittings-1.snapshot.27/2020 Extrusion Inside Corner Bracket.step
downloads/2020-extrusions-fittings-1.snapshot.27/2020 Extrusion Straight Internal Connector.step
downloads/2020-extrusions-fittings-1.snapshot.27/2040 Extrusion.step
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

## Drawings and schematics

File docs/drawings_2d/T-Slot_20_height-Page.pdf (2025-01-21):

20

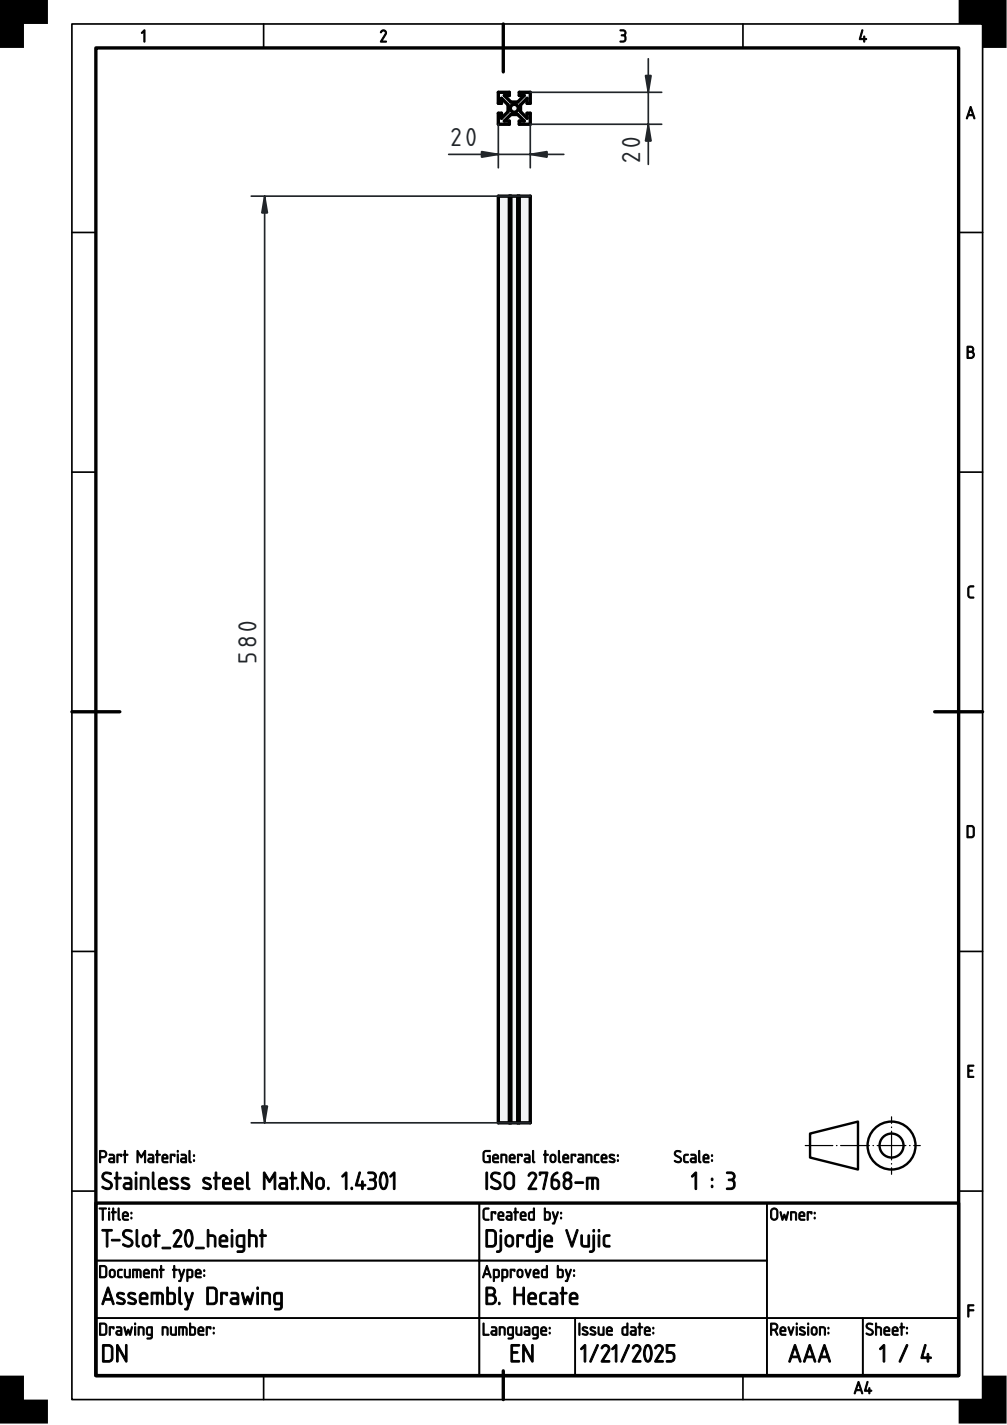
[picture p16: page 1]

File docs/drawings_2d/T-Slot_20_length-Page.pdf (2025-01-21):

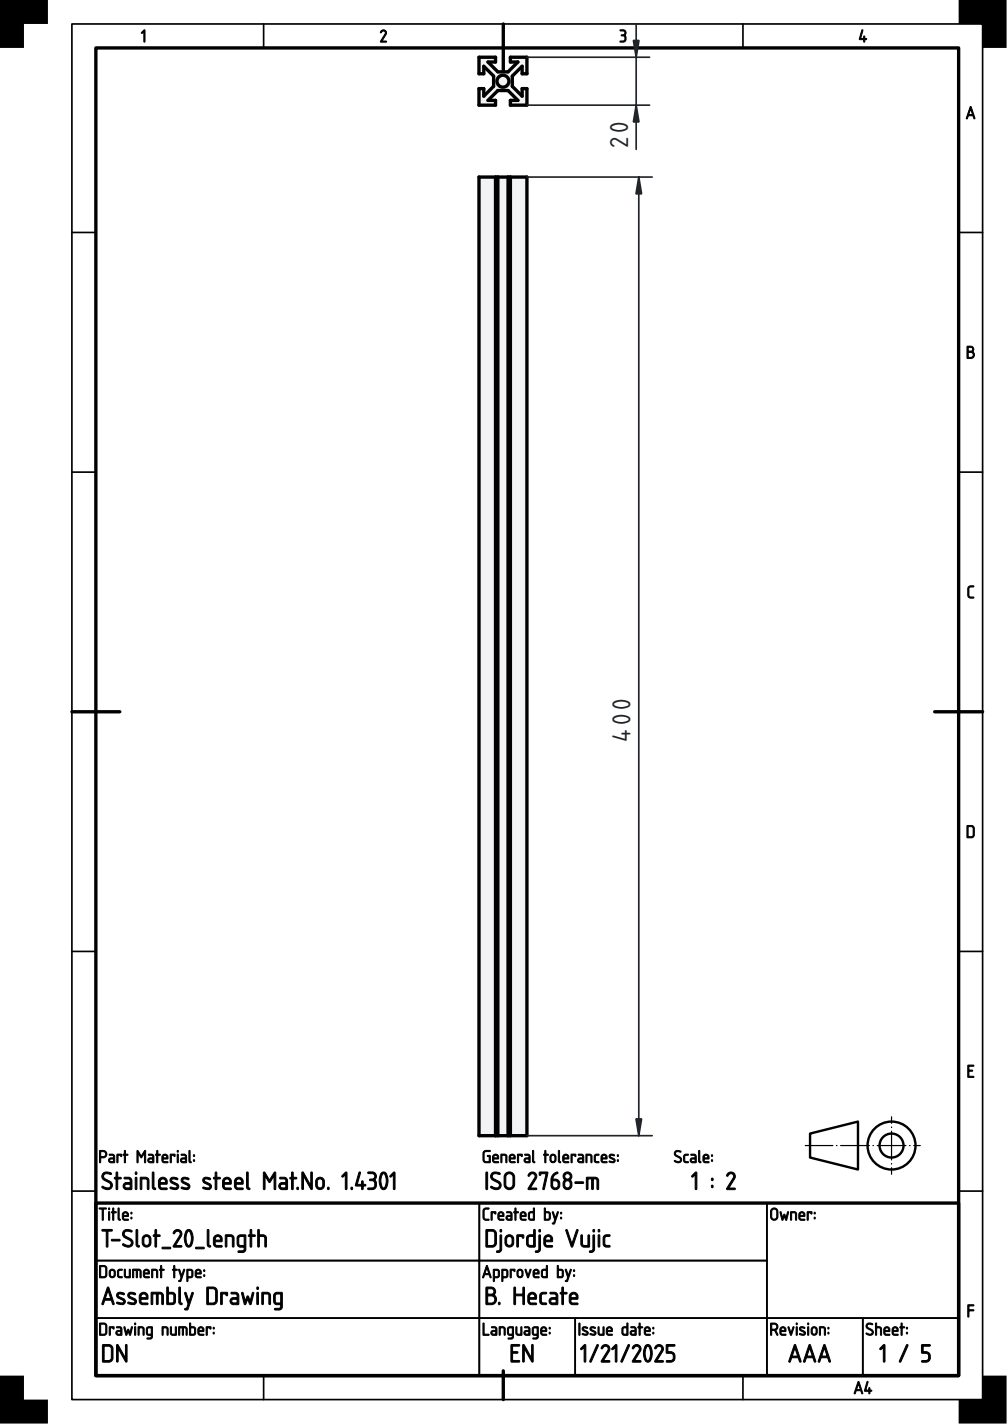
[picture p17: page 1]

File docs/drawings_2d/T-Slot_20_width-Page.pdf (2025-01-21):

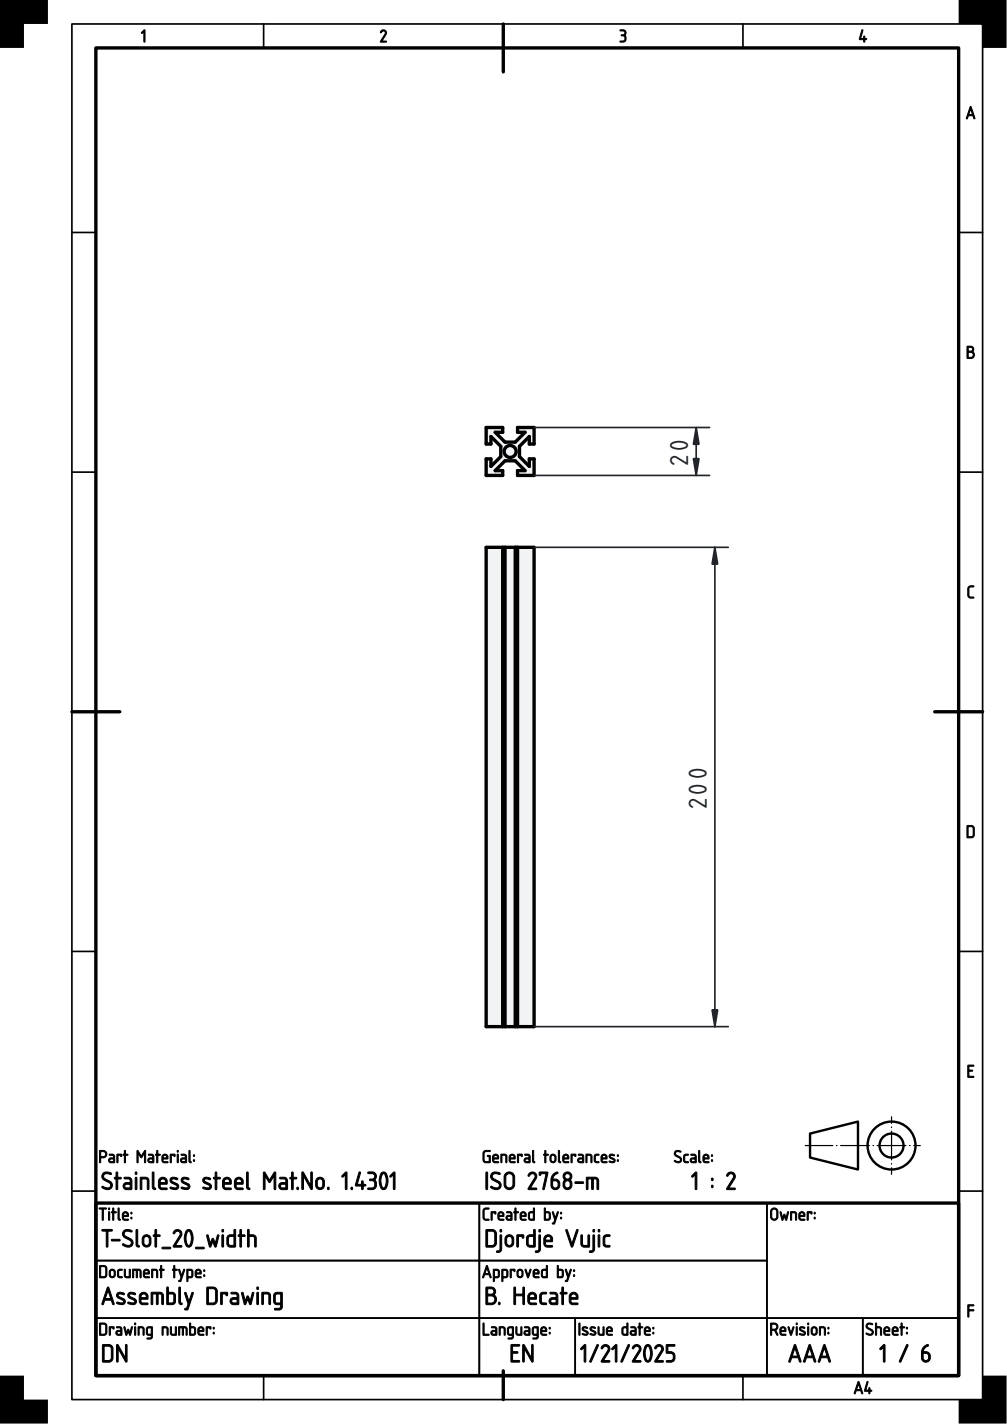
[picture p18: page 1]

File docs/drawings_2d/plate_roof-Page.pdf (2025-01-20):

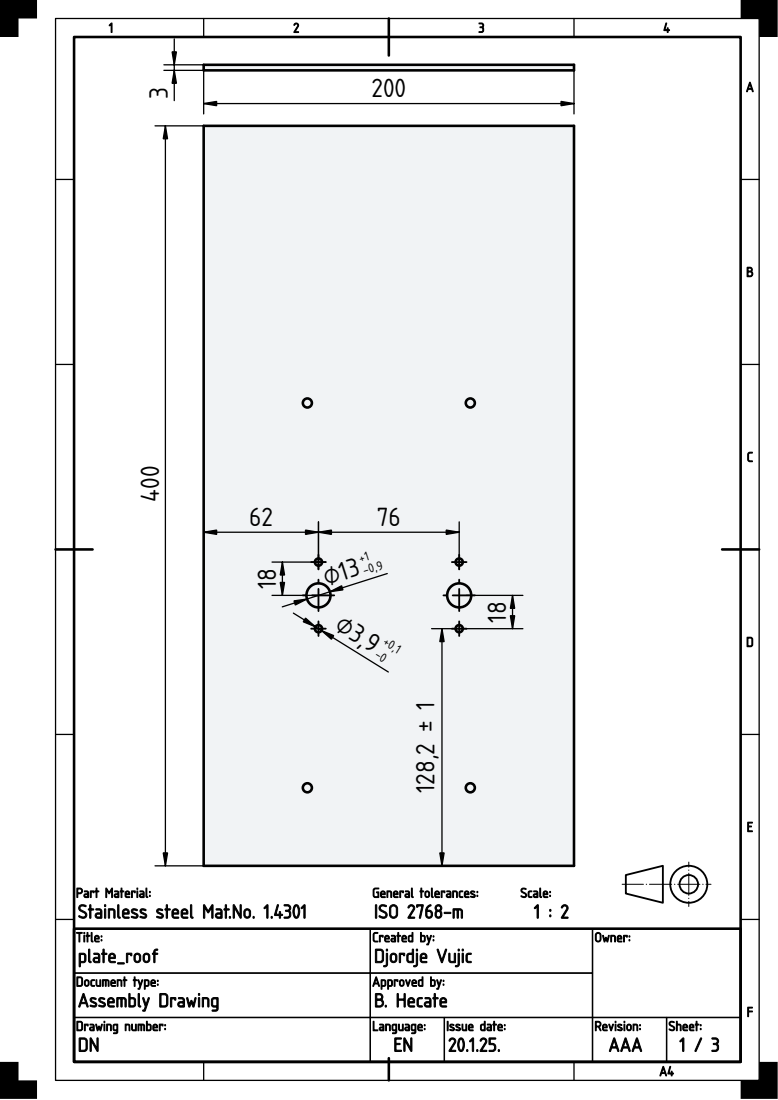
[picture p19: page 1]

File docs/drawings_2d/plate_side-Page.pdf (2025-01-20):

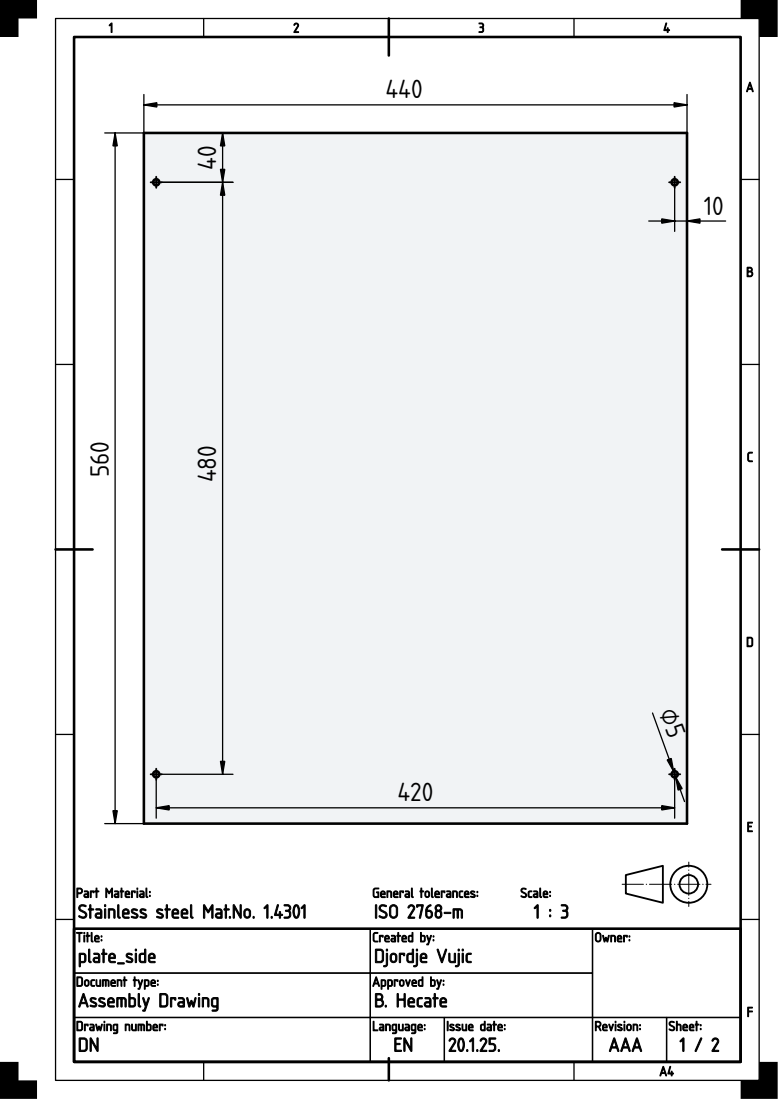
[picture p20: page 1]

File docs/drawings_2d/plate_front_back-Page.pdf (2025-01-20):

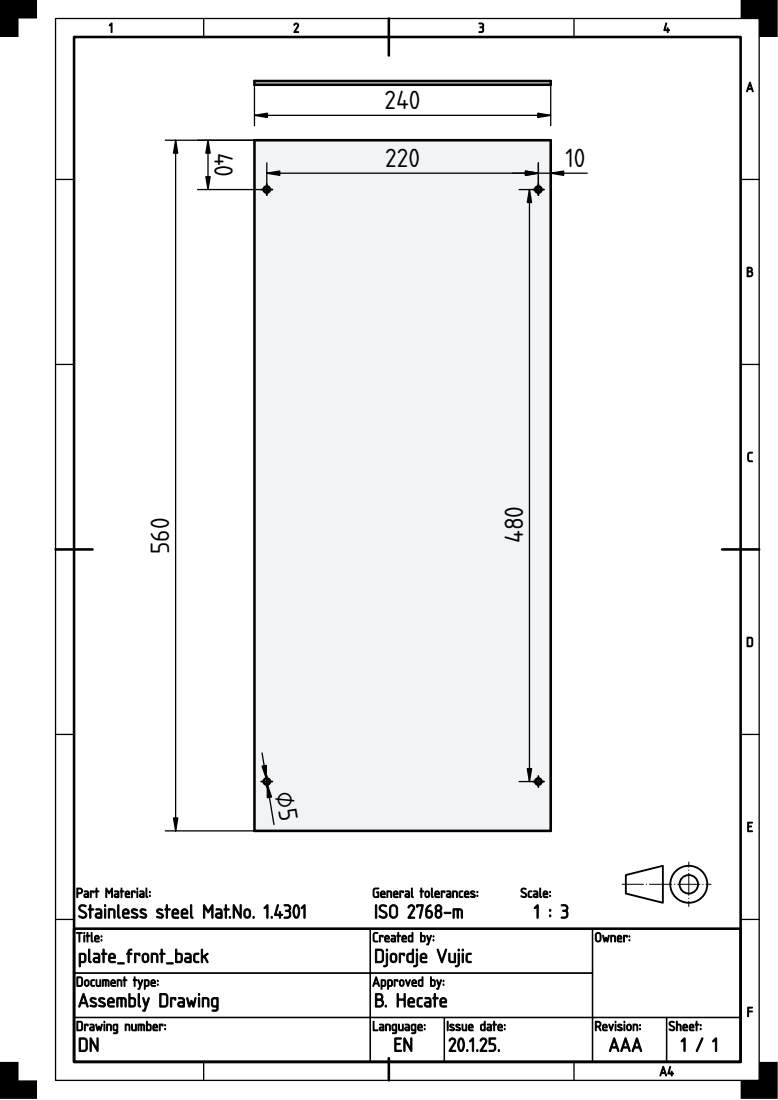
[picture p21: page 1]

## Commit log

2025-01-12 TAH15 M5 L6 bolt used for T profiles
    [TAH15-M5-L6.stp, TAH15_M5_L6.FCStd]
2025-01-12 Side plates added
    Front & back plates redimensioned
    gitignore
    [TAH15_M5_L6.FCStd, asm_plate_front_back.FCStd, asm_plate_side.FCStd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]
2025-01-14 nuts and bolts added to all corner connectors
    [dbox_asm.FCStd]
2025-01-15 Hexagonal nuts added to the roof assembly
    [asm_roof.FCStd, nuts_hexagonal.FCStd]
2025-01-18 Documentation added
    [BOM_DBOX.csv, BOM_DBOX_CUSTOM.csv, BOM_DBOX_MODIFIED.csv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]
2025-01-18 roof holder thickness decreased by from 8 to 6 mm
    [roof_holder.FCStd]
2025-01-18 2D drawings of plates
2025-01-18 part ordering documentation
    [BOM_DBOX_CUSTOM.csv, dbox_part_order.ods]
2025-01-20 roof-holder thickness decreased
    [roof_holder_asm.FCStd]
2025-01-20 Height decreased by 20 mm
    [T-Slot_20_height.FCStd, dbox_asm.FCStd, plate_front_back.FCStd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]
2025-01-20 plate front-back technical drawing
    [plate_front_back.FCStd]
2025-01-20 plate_side drawing
    [plate_front_back.FCStd, plate_side.FCStd]
2025-01-20 plate roof drawing
    [plate_roof.FCStd]
2025-01-20 plate roof after saving
    [plate_roof.FCStd]
2025-01-21 T-slot drawings added
    [T-Slot_20_height.FCStd, T-Slot_20_length.FCStd, T-Slot_20_width.FCStd]
2025-01-22 Order details and .step files for plates (plexiglas parts)
    [dbox_part_order.ods, plate_front_back-plate_front_back.step, plate_roof-plate_roof.step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]
2025-01-22 cam_holder_plate gcode and stl file
    [cam_holder_plate-cam_holder_plate.stl]
2025-01-22 added picture of the assembly, updated readme.md
2025-01-29 camera holder plate thinned to 3 mm
    [asm_cam_holder.FCStd, cam_holder_plate.FCStd, dbox_asm.FCStd]

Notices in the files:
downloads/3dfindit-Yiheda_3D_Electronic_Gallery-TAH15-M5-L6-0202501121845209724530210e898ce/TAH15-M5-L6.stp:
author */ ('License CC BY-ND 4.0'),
